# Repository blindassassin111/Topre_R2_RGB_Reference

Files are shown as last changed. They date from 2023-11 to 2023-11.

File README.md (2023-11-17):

# Topre_R2_RGB_Reference
Reference files for the Topre R2 RGB keyboards. Includes cutouts and models for 1U, and 2U, plus cutouts for 3U, and 7U/10U.

**Important Notes:**

- RGB plate cutouts are offset from switch center by 0.2mm, so make 100% sure that you follow the centerpoint shown in the cutout files for the exact center you should reference.
- RGB stabs are offset from the normal MX spacing due to topre housings being too wide to fit in the MX spacing of 0.94in(23.876mm) center to center (for 2U). They are instead 28.276mm (for 2U), or each stem is offset by 2.2mm. This can be extrapolated to other widths as well, just add 4.4mm total or add the 2.2mm to each side from center.
- RGB stabs do require custom wires as they are only 1mm(0.039in) thick instead of 1.58mm - 1.6mm(0.062in - 0.063in) like MX stab wires. As well as they are wider, due to the offset mentioned above, and they have longer legs to go in the stabs.

- RGB housings are designed to have the LED cutout north side, and stabs north side as well. In the cases where this isn't possible (example 2U backspace can be an issue with cases) you will need to flip the stabs and the switches immediately below that row. You may need to flip more than just the row below depending, but you can have two LED cutouts facing each other as you can get away with it in most offsets and even in situations where they do hit (the LED cutouts are inline) then you can trim the protrusion on the housing as it is only used for LED light redirection (it is an RGB LED light pipe afterall).
- When flipping stabs/cutouts **ALWAYS** reference the offset center as not doing that will cause the offset to double in the wrong direction and bind horribly. So please, always double/triple check.

- CAD models aren't 100% accurate but are the best I was able to measure and will function for testing/reference and possibly more but I make no guarantee of the accuracy of every single detail that you might be interested in knowing.

- Wire Bender is designed to work with the following wire bender: https://www.dubro.com/products/e-z-bender-wire-forming-tool?variant=27880341575
- Bender only uses the base and forming die and replaces the handle with two in order to properly bend wires to the correct length.
- No tutorials on how to use it, learn/test at your own risk. Use 1mm or 0.039in music wire for best results.

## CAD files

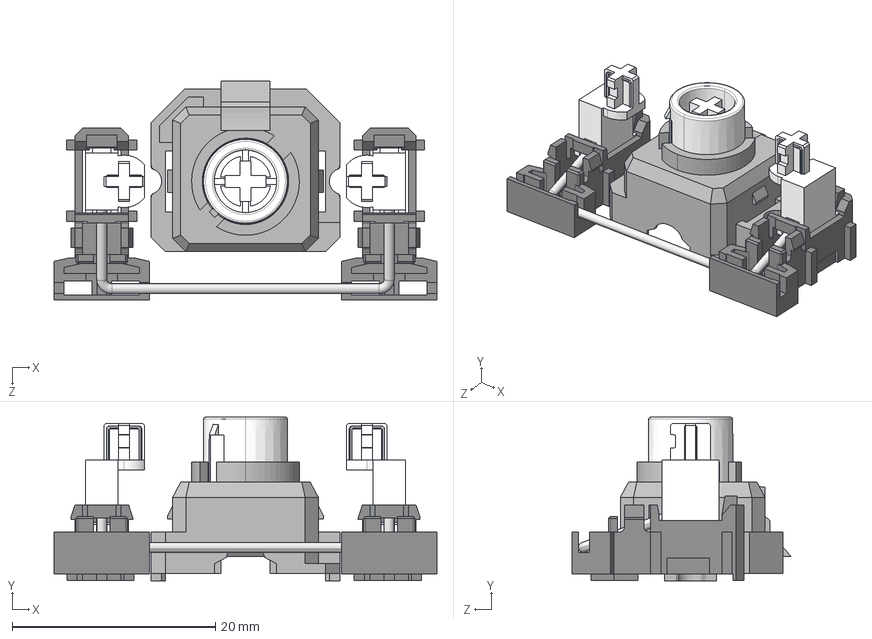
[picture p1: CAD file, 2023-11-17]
CAD_Models/R2_RGB_2U-South_Stab_Asm.STEP
37.7 x 16.1 x 21.6 mm
RGB_Stab_Housing x 2
RGB_Stab_Insert_Left
RGB_Stab_Insert_Right
R2_RGB_Topre_2U_Wire
RGB_Topre_Housing
RGB_Slider

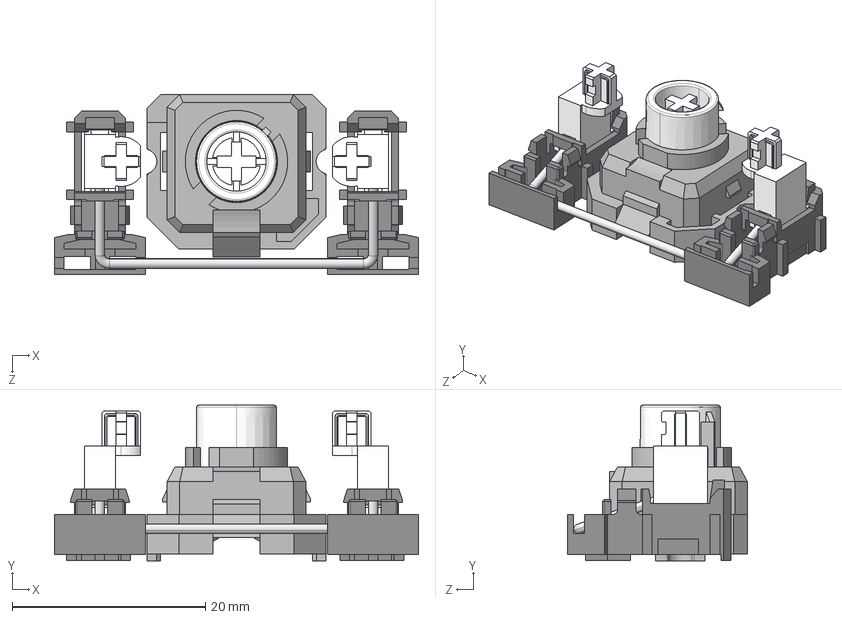
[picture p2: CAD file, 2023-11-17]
CAD_Models/R2_RGB_2U-North_Stab_Asm.STEP
37.7 x 16.1 x 18.6 mm
RGB_Stab_Housing x 2
RGB_Stab_Insert_Left
RGB_Stab_Insert_Right
R2_RGB_Topre_2U_Wire
RGB_Topre_Housing
RGB_Slider

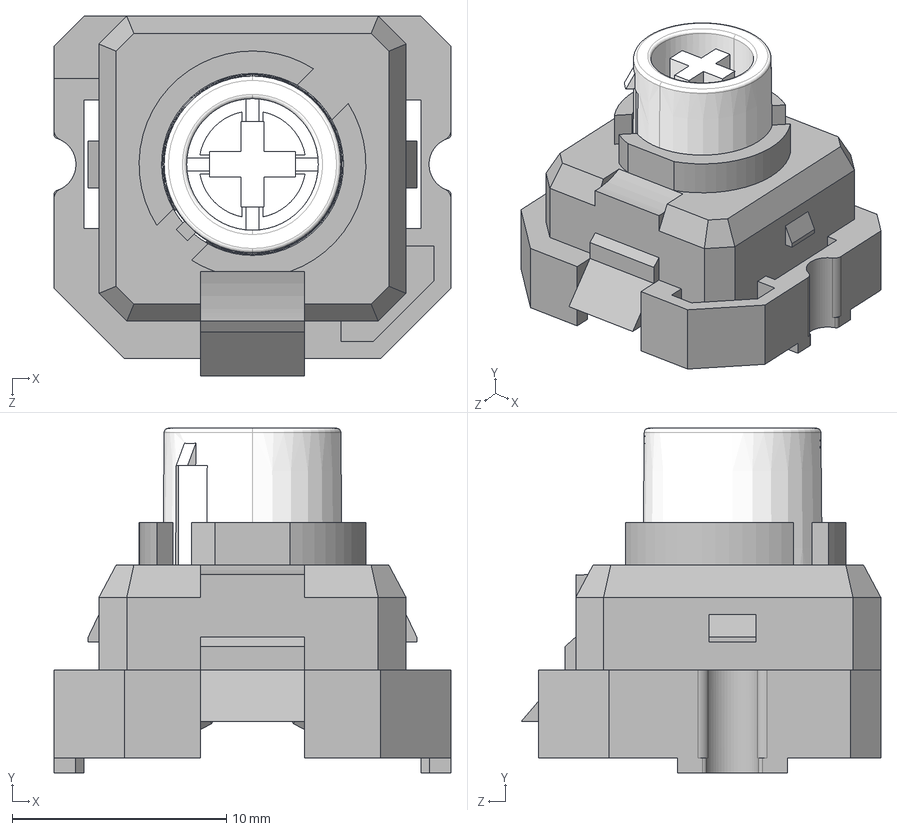
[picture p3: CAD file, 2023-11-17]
CAD_Models/R2_RGB_1U_Asm.STEP
18.6 x 16.1 x 16.8 mm
RGB_Topre_Housing
RGB_Slider

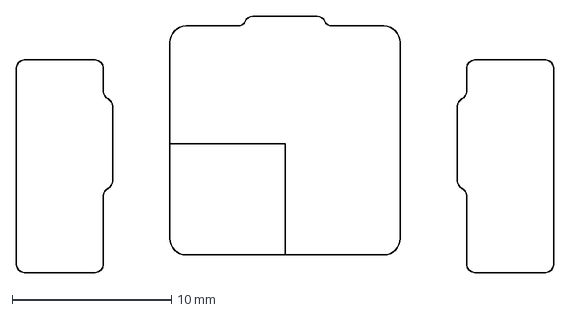
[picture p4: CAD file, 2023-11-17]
Plate_Cutouts/R2_RGB_2U-South_Stab_Cutout.DXF
33.7 x 16.1 mm

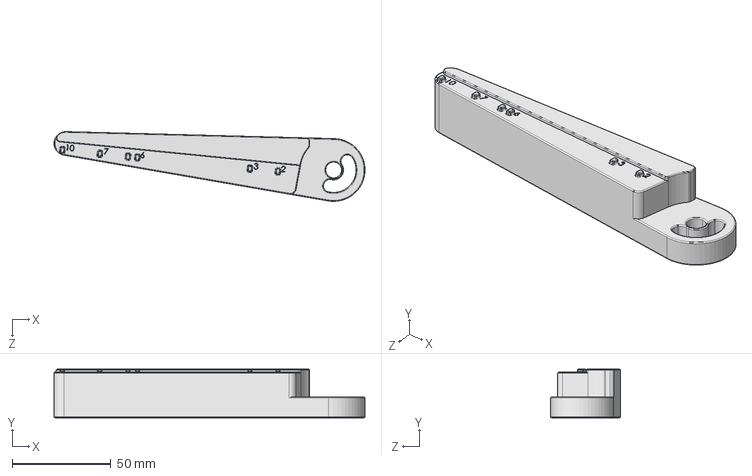
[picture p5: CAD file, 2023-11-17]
Stab_Wire_Bender/R2_RGB_Wire_Bender_Guide.STEP
157.2 x 24.5 x 35.3 mm

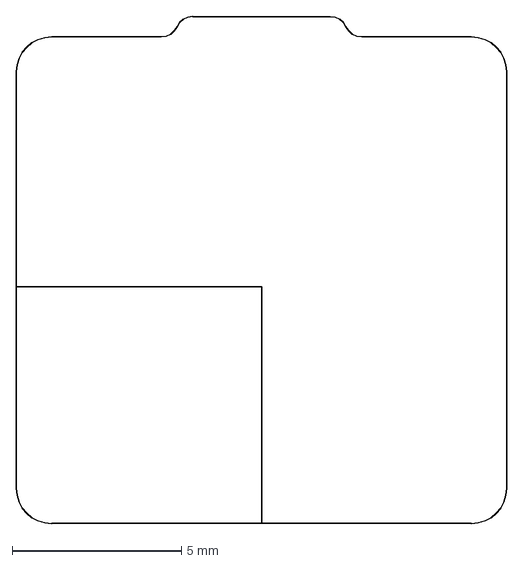
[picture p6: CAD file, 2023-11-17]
Plate_Cutouts/R2_RGB_1U_Cutout.DXF
14.5 x 15.0 mm

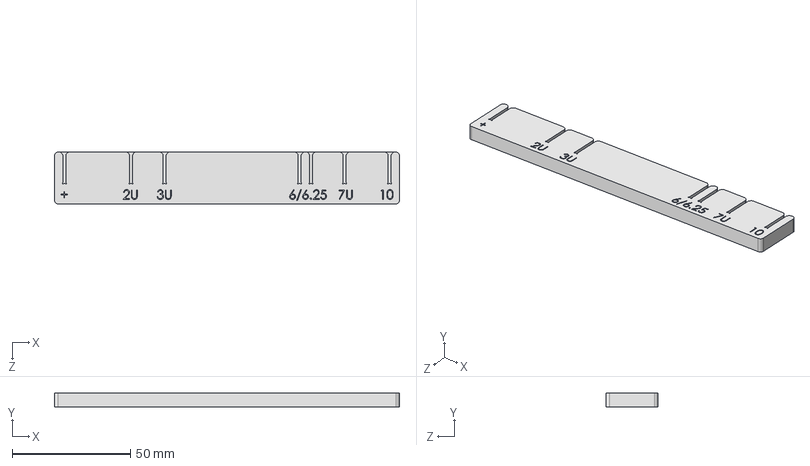
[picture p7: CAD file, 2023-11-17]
Stab_Wire_Bender/R2_RGB_Topre_Wire_Gauge.STEP
146.0 x 6.00 x 22.0 mm

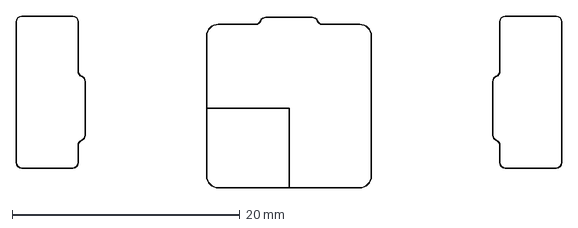
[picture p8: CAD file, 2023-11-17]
Plate_Cutouts/R2_RGB_3U-North_Stab_Cutout.DXF
48.0 x 15.1 mm

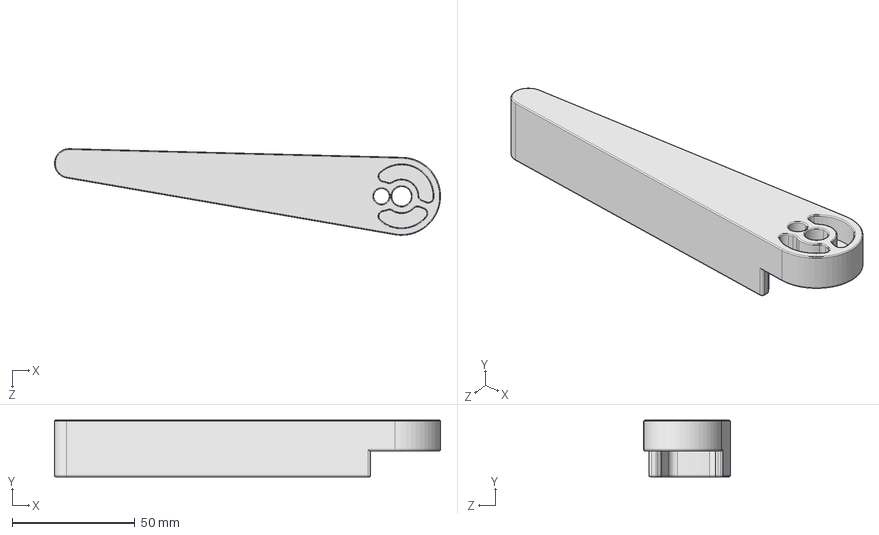
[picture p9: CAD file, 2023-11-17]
Stab_Wire_Bender/R2_RGB_Wire_Bender.STEP
157.2 x 23.0 x 35.3 mm

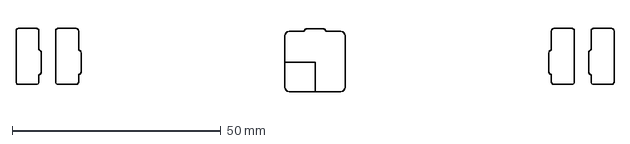
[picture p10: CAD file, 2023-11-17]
Plate_Cutouts/R2_RGB_7U-10U-North_Stab_Cutout.DXF
143.2 x 15.1 mm

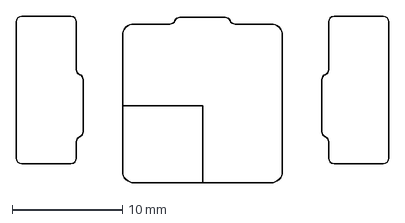
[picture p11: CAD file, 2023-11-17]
Plate_Cutouts/R2_RGB_2U-North_Stab_Cutout.DXF
33.7 x 15.1 mm

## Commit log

2023-11-17 Updating File Structure
    [R2_RGB_1U_Asm.STEP, R2_RGB_1U_Cutout.DXF, R2_RGB_2U-North_Stab_Asm.STEP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]
2023-11-17 Adding Stab Wire Bender
    [R2_RGB_Topre_Wire_Gauge.STEP, R2_RGB_Wire_Bender.STEP, R2_RGB_Wire_Bender_Guide.STEP]
